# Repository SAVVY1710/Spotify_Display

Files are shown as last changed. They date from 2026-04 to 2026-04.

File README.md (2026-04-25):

# Spotify Display
A compact ESP32-powered display that shows your currently playing Spotify track including 
the song name, artist, and album art on a 3.5" TFT screen, all housed in a custom 
3D-printed case. Features a rotary encoder for volume control and 3 mechanical keyboard 
switches for playback controls.

## Why I Made This
I wanted a physical, always-on display sitting on my desk that shows what I'm listening 
to without having to look at my phone or computer.

## 3D Model



This is an image of my CAD for the project and as you can see, it has specific places 
where I can insert the keys, the ESP32, the rotary encoder, and the screen. It's 
efficient because you will see none of the wires and will be left with a clean looking 
display.

## Wiring Diagram


### TFT Display
| TFT Pin  | ESP32 Pin |
|---|---|
| CS | GPIO 0 |
| RST | GPIO 1 |
| DC/RS | GPIO 2 |
| SDI/MOSI | GPIO 3 |
| SCK | GPIO 4 |
| VCC | 3.3V |
| GND | GND |
| LED | 3.3V |

### Keyboard Switches
Each switch has two legs. One leg connects to a GPIO pin, the other to GND.
The firmware uses the ESP32's internal pull-up resistors, so no external resistors are needed.

| Switch | Function | ESP32 Pin | Other Leg |
|---|---|---|---|
| Switch 1 | Play/Pause | GPIO 5 | GND |
| Switch 2 | Skip | GPIO 6 | GND |
| Switch 3 | Previous | GPIO 7 | GND |

### Rotary Encoder
The rotary encoder controls volume. Rotating clockwise increases volume, 
counter-clockwise decreases it. Pressing the encoder click acts as an 
additional play/pause button.

| Encoder Pin | ESP32 Pin |
|---|---|
| CLK | GPIO 8 |
| DT | GPIO 10 | 
| VCC | 3.3V |
| GND | GND |

## Features
- Displays current song name and artist pulled live from Spotify
- Renders album art as a scaled JPEG on the 3.5" TFT screen
- 3 mechanical keyboard switches for playback controls (play/pause, skip, previous)
- Rotary encoder for smooth volume control
- Boot animation on startup
- Custom 3D-printed enclosure designed in Fusion360
- Auto-reconnects and polls Spotify every 2 seconds

## Setup

### Hardware
- ESP32 LOLIN C3 Mini
- 3.5" ILI9341 TFT display
- 3x mechanical keyboard switches
- 1x rotary encoder (KY-040 or EC11)
- 3D-printed case (see `/cad` folder)

### Software
1. Install [Arduino IDE](https://www.arduino.cc/en/software/)
2. Install the ESP32 board via Board Manager
3. Install libraries:
   - `SpotifyEsp32` (from `/libraries` folder or as .zip)
   - `Adafruit_ILI9341`
   - `Adafruit_GFX`
   - `JPEGDecoder`
4. Create a Spotify app at [developer.spotify.com](https://developer.spotify.com) 
   and copy your Client ID and Client Secret
5. Fill in your WiFi credentials and Spotify credentials in the sketch
6. Upload, note the IP shown on screen, and set your Spotify redirect URI 
   to `http://<that-ip>/callback`
7. Open that URL in a browser on the same network to authenticate

## Bill of Materials

| Item | Quantity | Unit Price |
|---|---|---|
| ESP32 LOLIN C3 Mini | 1 | $5.66 |
| 3.5" ILI9341 TFT Display | 1 | $8.18 |
| Mechanical Keyboard Switches | 1 pack | $0.99 |
| Rotary Encoder | 1 | $2.34 |
| **Total** | | **$17.17** |

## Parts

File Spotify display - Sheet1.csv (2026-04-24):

Part: | Quantity: | Cost: | Link:
Screen | 1 | 8.18 | https://www.aliexpress.us/item/3256809260879179.html?src=google&snpsid=1&gatewayAdapt=glo2usa
ESP32 | 1 | 5.66 | https://www.aliexpress.us/item/3256804553736450.html?gatewayAdapt=glo2usa4itemAdapt
Switches | 1 | 0.99 | https://www.aliexpress.us/item/3256811652574937.html?curPageLogUid=0lOA5pbHysJu
Rotary Encoder | 1 | 2.34 | aliexpress.us/item/3256808610376268.html?spm=a2g0o.cart.0.0.31f938darYbFWj&mp=1&pdp_npi=6%40dis%21USD%21USD%204.98%21USD%202.34%21%21USD%202.34%21%21%21%402103212517770643431426772eb7a4%2112000046699869229%21ct%21US%217547717759%21%211%210%21&gatewayAdapt=glo2usa&_randl_shipto=US

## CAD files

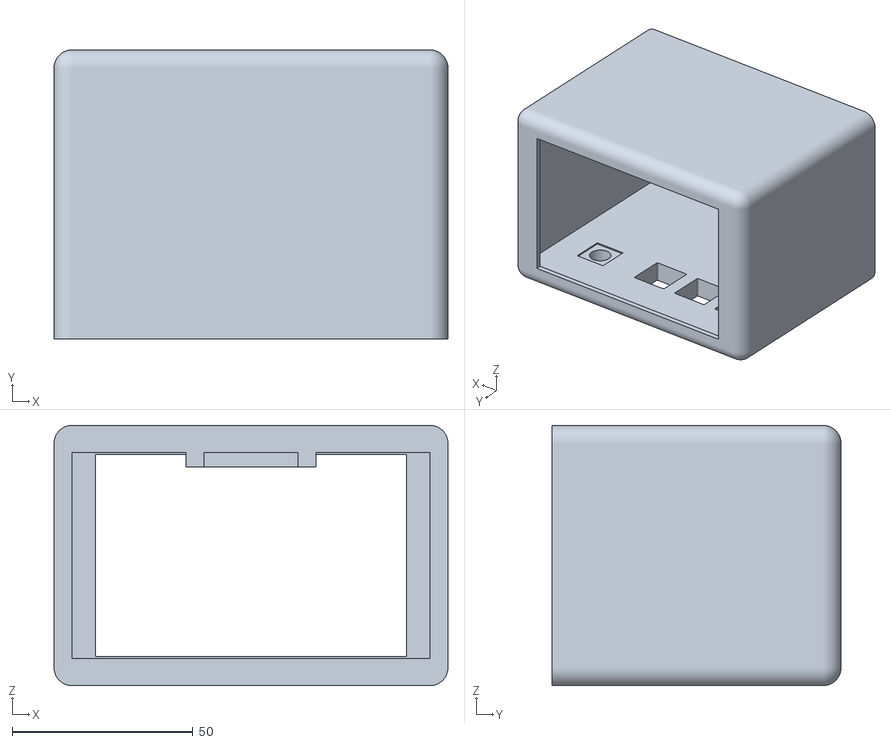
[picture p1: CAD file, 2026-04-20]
CAD/Part Studio 1 - Part 1.stl
109.0 x 80.0 x 72.0

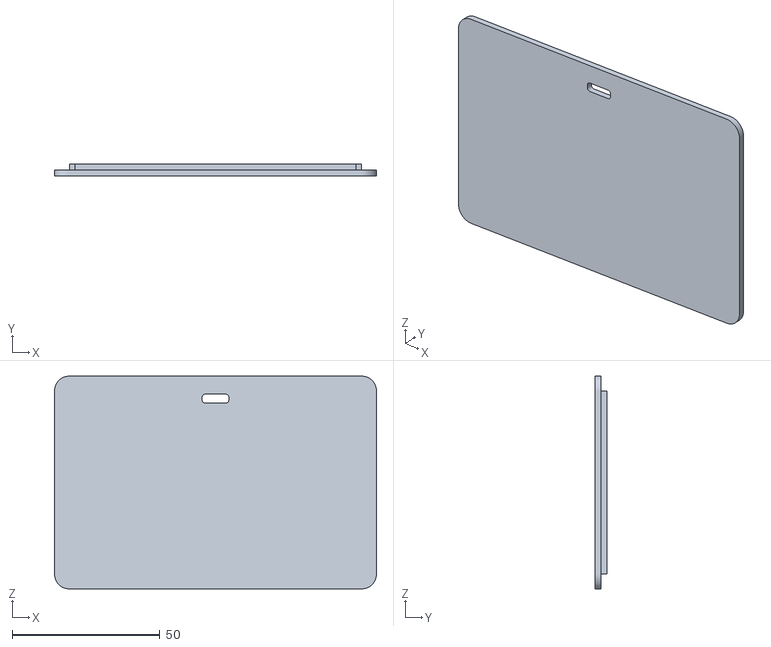
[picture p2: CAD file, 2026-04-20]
CAD/Part Studio 1 - Part 2.stl
109.0 x 4.00 x 72.0

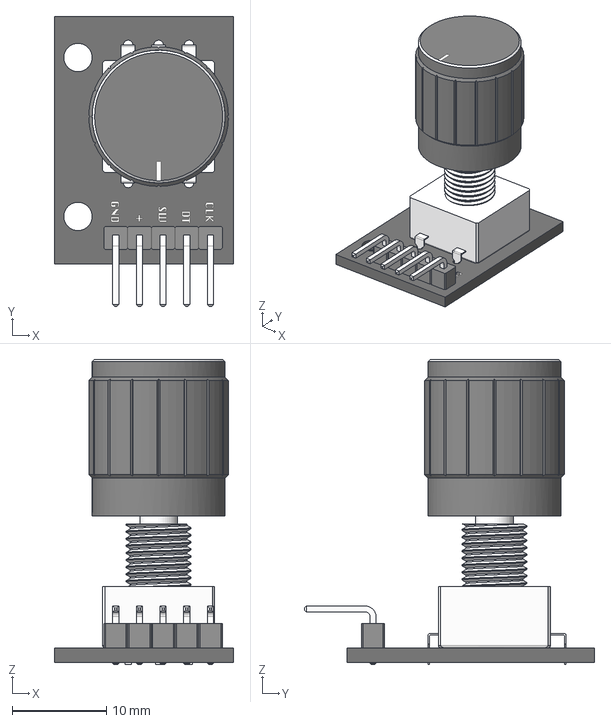
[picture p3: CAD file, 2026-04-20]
CAD/Rotary Encoder - KY-040.step
19.0 x 30.8 x 32.4 mm

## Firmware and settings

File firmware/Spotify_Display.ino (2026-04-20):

#include <Arduino.h>
#include <ArduinoJson.h>
#include <Adafruit_GFX.h>
#include <Adafruit_ILI9341.h>  // changed from ST7735 to ILI9341 for 3.5" screen
#include <WiFi.h>
#include <SpotifyEsp32.h>
#include <SPI.h>
#include <HTTPClient.h>
#include <JPEGDecoder.h>

// --- TFT Pin Definitions ---
#define TFT_CS    0
#define TFT_RST   1
#define TFT_DC    2
#define TFT_MOSI  3
#define TFT_SCLK  4

// --- Button Pin Definitions ---
#define BTN_PLAYPAUSE 5
#define BTN_SKIP      6
#define BTN_PREVIOUS  7

// --- Rotary Encoder Pin Definitions ---
#define ENC_CLK   8
#define ENC_DT    9
#define ENC_SW    10

// --- Credentials ---
char*       SSID          = "YOUR_WIFI_SSID";
char*       PASSWORD      = "YOUR_WIFI_PASSWORD";
const char* CLIENT_ID     = "1e7799fcda8b4b27bb4e4ebc03d721e6";
const char* CLIENT_SECRET = "Y7ef91d4642fb48039a2cd1e88cb279b3";

// --- Objects ---
Spotify          sp(CLIENT_ID, CLIENT_SECRET);
Adafruit_ILI9341 tft = Adafruit_ILI9341(TFT_CS, TFT_DC, TFT_MOSI, TFT_SCLK, TFT_RST);

// --- State ---
String lastArtist   = "";
String lastTrack    = "";
String lastImageUrl = "";
int    volume       = 50; // default volume 0-100

// --- Encoder state ---
int  lastEncCLK      = HIGH;
long lastEncTime     = 0;
bool lastSwState     = HIGH;
long lastSwTime      = 0;

// --- Layout (320x480 landscape = 480 wide, 320 tall) ---
#define ART_X    0
#define ART_Y    0
#define ART_SIZE 160   // bigger art for bigger screen
#define TEXT_X   170
#define TEXT_W   (480 - TEXT_X)

// -----------------------------------------------------------
// Fetch JPEG from URL into heap buffer
// -----------------------------------------------------------
uint8_t* fetchJpeg(const String& url, int& outSize) {
    HTTPClient http;
    http.begin(url);
    int httpCode = http.GET();

    if (httpCode != HTTP_CODE_OK) {
        Serial.printf("Image fetch failed, HTTP code: %d\n", httpCode);
        http.end();
        return nullptr;
    }

    int len = http.getSize();
    if (len <= 0 || len > 60000) {  // increased limit for bigger screen
        Serial.printf("Image size out of range: %d bytes\n", len);
        http.end();
        return nullptr;
    }

    uint8_t* buf = (uint8_t*)malloc(len);
    if (!buf) {
        Serial.println("malloc failed — not enough heap");
        http.end();
        return nullptr;
    }

    WiFiClient* stream = http.getStreamPtr();
    int bytesRead = 0;
    unsigned long timeout = millis() + 5000;
    while (bytesRead < len && millis() < timeout) {
        int avail = stream->available();
        if (avail > 0) {
            bytesRead += stream->readBytes(buf + bytesRead, avail);
        }
    }

    http.end();

    if (bytesRead < len) {
        Serial.println("Image download timed out");
        free(buf);
        return nullptr;
    }

    outSize = bytesRead;
    return buf;
}

// -----------------------------------------------------------
// Decode and draw JPEG scaled to ART_SIZE x ART_SIZE
// -----------------------------------------------------------
void drawJpeg(uint8_t* data, int size, int x, int y) {
    if (!JpegDec.decodeArray(data, size)) {
        Serial.println("JPEG decode failed");
        return;
    }

    int srcW = JpegDec.width;
    int srcH = JpegDec.height;

    while (JpegDec.read()) {
        uint16_t* pImg = JpegDec.pImage;
        int mcuX = JpegDec.MCUx * JpegDec.MCUWidth;
        int mcuY = JpegDec.MCUy * JpegDec.MCUHeight;

        for (int row = 0; row < JpegDec.MCUHeight; row++) {
            for (int col = 0; col < JpegDec.MCUWidth; col++) {
                int srcPxX = mcuX + col;
                int srcPxY = mcuY + row;

                int dstX = x + (srcPxX * ART_SIZE) / srcW;
                int dstY = y + (srcPxY * ART_SIZE) / srcH;

                if (dstX < x + ART_SIZE && dstY < y + ART_SIZE) {
                    uint16_t color = pImg[row * JpegDec.MCUWidth + col];
                    color = (color >> 8) | (color << 8);
                    tft.drawPixel(dstX, dstY, color);
                }
            }
        }
    }
}

// -----------------------------------------------------------
// Fetch and render album art
// -----------------------------------------------------------
void updateAlbumArt(const String& url) {
    if (url.isEmpty() || url == "Something went wrong") return;

    Serial.println("Fetching album art...");
    int jpegSize = 0;
    // use index 1 (medium ~300px) since screen is bigger now
    uint8_t* jpegData = fetchJpeg(url, jpegSize);

    if (jpegData) {
        tft.fillRect(ART_X, ART_Y, ART_SIZE, ART_SIZE, ILI9341_BLACK);
        drawJpeg(jpegData, jpegSize, ART_X, ART_Y);
        free(jpegData);
        Serial.println("Album art drawn!");
    } else {
        Serial.println("Could not draw album art");
    }
}

// -----------------------------------------------------------
// Clear a region and print text
// -----------------------------------------------------------
void drawText(int x, int y, int w, int h,
              const String& text, uint8_t size, uint16_t color) {
    tft.fillRect(x, y, w, h, ILI9341_BLACK);
    tft.setCursor(x, y);
    tft.setTextSize(size);
    tft.setTextColor(color);
    tft.setTextWrap(true);
    tft.write(text.c_str());
}

// -----------------------------------------------------------
// Draw volume bar on screen
// -----------------------------------------------------------
void drawVolumeBar(int vol) {
    int barX    = TEXT_X;
    int barY    = 280;
    int barMaxW = TEXT_W - 10;
    int barH    = 12;
    int fillW   = (vol * barMaxW) / 100;

    // background
    tft.fillRect(barX, barY, barMaxW, barH, ILI9341_DARKGREY);
    // fill
    tft.fillRect(barX, barY, fillW, barH, ILI9341_GREEN);
    // label
    tft.setCursor(barX, barY - 16);
    tft.setTextSize(1);
    tft.setTextColor(ILI9341_WHITE);
    tft.fillRect(barX, barY - 16, 60, 10, ILI9341_BLACK);
    tft.print("Vol: " + String(vol) + "%");
}

// -----------------------------------------------------------
// Boot animation
// -----------------------------------------------------------
void drawBootAnimation() {
    tft.fillScreen(ILI9341_BLACK);

    int cx = 240, cy = 160; // center of 480x320

    // grow circle
    for (int r = 0; r <= 80; r += 3) {
        tft.drawCircle(cx, cy, r, ILI9341_GREEN);
        delay(20);
    }
    tft.fillCircle(cx, cy, 80, ILI9341_GREEN);
    delay(100);

    // draw 3 equalizer bars
    int barW    = 18;
    int barGap  = 10;
    int barBaseY = cy + 25;
    int heights[] = {45, 60, 38};
    int startX  = cx - (3 * barW + 2 * barGap) / 2;

    for (int i = 0; i < 3; i++) {
        int bx = startX + i * (barW + barGap);
        tft.fillRect(bx, barBaseY - heights[i], barW, heights[i], ILI9341_WHITE);
        delay(80);
    }

    delay(600);

    // animate bars
    for (int anim = 0; anim < 4; anim++) {
        int newHeights[] = {
            (anim % 2 == 0) ? 30 : 55,
            (anim % 2 == 0) ? 58 : 28,
            (anim % 2 == 0) ? 48 : 38
        };
        tft.fillCircle(cx, cy, 80, ILI9341_GREEN);
        for (int i = 0; i < 3; i++) {
            int bx = startX + i * (barW + barGap);
            tft.fillRect(bx, barBaseY - newHeights[i], barW, newHeights[i], ILI9341_WHITE);
        }
        delay(150);
    }

    delay(400);

    // shrink circle
    for (int r = 80; r >= 0; r -= 4) {
        tft.fillCircle(cx, cy, r + 4, ILI9341_BLACK);
        tft.fillCircle(cx, cy, r, ILI9341_GREEN);
        delay(20);
    }
    tft.fillScreen(ILI9341_BLACK);
    delay(200);
}

// -----------------------------------------------------------
// Handle rotary encoder for volume
// -----------------------------------------------------------
void handleEncoder() {
    int clkState = digitalRead(ENC_CLK);
    long now = millis();

    // Rotation — debounce 5ms
    if (clkState != lastEncCLK && (now - lastEncTime) > 5) {
        lastEncTime = now;
        if (digitalRead(ENC_DT) != clkState) {
            // clockwise — volume up
            volume = min(100, volume + 5);
        } else {
            // counter-clockwise — volume down
            volume = max(0, volume - 5);
        }
        sp.set_volume(volume);
        drawVolumeBar(volume);
        Serial.println("Volume: " + String(volume));
    }
    lastEncCLK = clkState;

    // Click — debounce 200ms
    bool swState = digitalRead(ENC_SW);
    if (swState == LOW && lastSwState == HIGH && (now - lastSwTime) > 200) {
        lastSwTime = now;
        sp.start_a_users_playback();
        Serial.println("Encoder click: play/pause");
    }
    lastSwState = swState;
}

// -----------------------------------------------------------
// SETUP
// -----------------------------------------------------------
void setup() {
    Serial.begin(115200);

    // Button pins
    pinMode(BTN_PLAYPAUSE, INPUT_PULLUP);
    pinMode(BTN_SKIP,      INPUT_PULLUP);
    pinMode(BTN_PREVIOUS,  INPUT_PULLUP);

    // Encoder pins
    pinMode(ENC_CLK, INPUT_PULLUP);
    pinMode(ENC_DT,  INPUT_PULLUP);
    pinMode(ENC_SW,  INPUT_PULLUP);

    // Init TFT
    tft.begin();
    tft.setRotation(1);         // landscape: 480 wide, 320 tall
    tft.fillScreen(ILI9341_BLACK);
    tft.setTextColor(ILI9341_WHITE);
    tft.setTextSize(1);
    Serial.println("TFT ready");

    // Boot animation
    drawBootAnimation();

    // Connect to WiFi
    tft.setCursor(0, 0);
    tft.setTextSize(2);
    tft.write("Connecting to WiFi...");
    WiFi.begin(SSID, PASSWORD);
    while (WiFi.status() != WL_CONNECTED) {
        delay(1000);
        Serial.print(".");
    }
    Serial.println("\nWiFi connected!");

    String ip = WiFi.localIP().toString();
    Serial.println("IP: " + ip);
    tft.fillScreen(ILI9341_BLACK);
    tft.setCursor(0, 0);
    tft.setTextSize(2);
    tft.write("WiFi connected!\nIP:\n");
    tft.write(ip.c_str());
    delay(3000);

    // Authenticate Spotify
    tft.fillScreen(ILI9341_BLACK);
    tft.setCursor(0, 0);
    tft.setTextSize(2);
    tft.write("Open browser:\n");
    tft.write(ip.c_str());
    tft.write("/callback\n\nto authenticate\nSpotify");

    sp.begin();
    while (!sp.is_auth()) {
        sp.handle_client();
    }
    Serial.println("Spotify authenticated!");

    tft.fillScreen(ILI9341_BLACK);
    tft.setCursor(0, 0);
    tft.setTextSize(2);
    tft.write("Spotify ready!");
    delay(1500);
    tft.fillScreen(ILI9341_BLACK);

    // Draw initial volume bar
    drawVolumeBar(volume);
}

// -----------------------------------------------------------
// LOOP
//
// Screen layout (480x320 landscape):
//  +---------+--------------------------------+
//  |         | Artist (green, size 3)         |
//  | 160x160 |                                |
//  |  art    | Track  (white, size 2)         |
//  |         |                                |
//  |         | [====volume bar====]           |
//  +---------+--------------------------------+
// -----------------------------------------------------------
void loop() {
    // --- Encoder ---
    handleEncoder();

    // --- Buttons ---
    if (digitalRead(BTN_PLAYPAUSE) == LOW) {
        sp.start_a_users_playback();
        delay(300);
    }
    if (digitalRead(BTN_SKIP) == LOW) {
        sp.skip_to_next();
        delay(300);
    }
    if (digitalRead(BTN_PREVIOUS) == LOW) {
        sp.skip_to_previous();
        delay(300);
    }

    // --- Spotify polling ---
    String currentArtist = sp.current_artist_names();
    String currentTrack  = sp.current_track_name();
    String currentUrl    = sp.get_current_album_image_url(1); // index 1 = medium for bigger screen

    bool trackChanged = (currentTrack  != lastTrack  &&
                         currentTrack  != "Something went wrong" &&
                         currentTrack  != "null" &&
                         !currentTrack.isEmpty());

    bool artistChanged = (currentArtist != lastArtist &&
                          currentArtist != "Something went wrong" &&
                          !currentArtist.isEmpty());

    if (trackChanged) {
        lastTrack = currentTrack;

        if (currentUrl != lastImageUrl && !currentUrl.isEmpty()) {
            lastImageUrl = currentUrl;
            updateAlbumArt(currentUrl);
        }

        Serial.println("Track: " + lastTrack);
        drawText(TEXT_X, 100, TEXT_W, 80, lastTrack, 2, ILI9341_WHITE);
    }

    if (artistChanged) {
        lastArtist = currentArtist;
        Serial.println("Artist: " + lastArtist);
        drawText(TEXT_X, 20, TEXT_W, 60, lastArtist, 3, ILI9341_GREEN);
    }

    delay(2000);
}

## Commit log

2026-04-13 Enhance README with project details and setup instructions
    Added detailed project description, wiring diagrams, features, setup instructions, and bill of materials for the Spotify Display project.
2026-04-14 Rename Assembly 1.step to SpotifyDisplayAssembly.step
    [SpotifyDisplayAssembly.step]
2026-04-14 Rename Spotify display - Sheet1.csv to BOM.csv
    [BOM.csv, Spotify display - Sheet1.csv]
2026-04-14 Update cost for Screen in BOM.csv
    [BOM.csv]
2026-04-14 Revise wiring and switch details in README.md
    Updated wiring diagram and switch configurations in README.
2026-04-14 Update GPIO pin assignments for switches in README
2026-04-14 Refactor pin definitions and update button handling
